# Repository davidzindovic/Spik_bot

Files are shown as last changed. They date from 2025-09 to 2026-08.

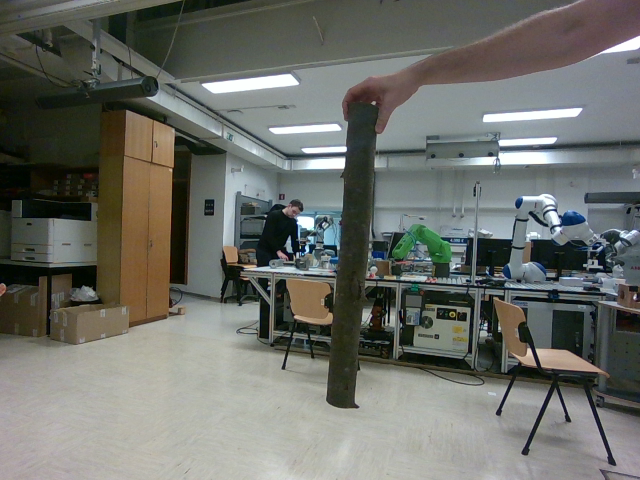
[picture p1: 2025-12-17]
RPI/zajeti_podatki/2barva.png

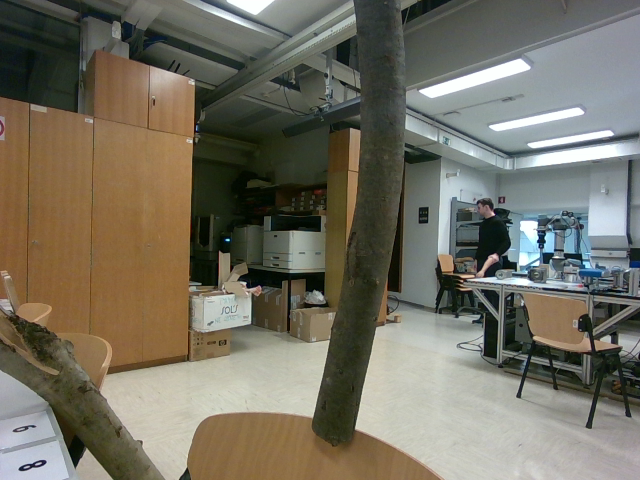
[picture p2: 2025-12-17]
RPI/zajeti_podatki/6barva.png

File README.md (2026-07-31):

# OPIS
SpikBot je manipulator namenjen robotizirani endoterapiji dreves, ki obratuje s pomočjo STM32H750B-DK razvojne plošče.
Drevo zazna s pomočjo Intel RealSense D455 RGB-D kamere, ki je povezana na osebni računalnik.
Po sadovnjaku premikamo manipulator s pomočjo AWD+AWS mobilne platforme, ki jo upravlja BeckHoff PLC krmilnik.

# REPOZITORIJ

- **Hardware** - Datoteke za električno shemo in električno vezje
- **Meritve** - Datoteke namenjene uvodnim meritvah sile in traja (arhivirano)
- **PC** - Programske datoteke, ki tečejo na osebnem računalniku
- **RPI** - Programske datoteke, ki tečejo na RaspberryPi (arhivirano)
- **STM32** - Programske datoteke, ki teče na STM32

# UPORABA

Napravo lahko uporabljamo v kombinaciji z računalnikom in STM32 krmilnikom preko tipkovnice.
Za Uporabo preko igralnega ploščka moramo povezati računalnik na mobilno platformo.
Navodila za uporabo se izpišejo ob začetku programa.

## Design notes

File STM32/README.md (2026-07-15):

Program deluje v okolju STM32CUBE_IDE različica ```1.16.1``` .

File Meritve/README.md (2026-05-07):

# Opis
Program beleži izmerjene podatke v .csv datoteko. Meritve opravlja STM32 razvojna plošča. Uporabnik lahko preko serijskega okna odprtega v Python okolju nastavlja željeni tlak in bere izmerjeni ter nastavjleni pritisk. Ob koncu programa (Ctrl+C) program shrani podatke in na podlagi shranjene .csv datoteke nariše grafikon.

## Potrebne knjižnice za zagon:
pyserial, matplotlib

## Sprememiti je potrebno:
- ```COM port (preverimo v Upravitelj naprav ali Device manager)```
- ```Pot do mape, v katero želimo shranjevati meritve```

# Potek meritve
Motor za vbod v deblo krmili bela ST razvojna plošča, pri čemer s pritiskom na modro tipko menjavamo smer potiska, s potenciometrom pa hitrost potiska.

Motor za črpalko krmili modra ST razvojna plošča z ekranom, ki tudi bere podatke iz senzorja (od primernega upora).

Za izvedbo meritve je potrebno vklopiti oba velika napajalnika na 230V, nato pa v poljubnem vrstnem redu še ST razvojni plošči (sta neodvisni ena od druge).

Ne pozabite tudi poskrbeti za primerno vmestitev dovodne cevi za tekočino (označena z maskircem in napisom "IN").

Zaženemo datoteko ```meritve_pritisk_stm32.py``` in spremljamo serijski monitor. Za vnos zaželjenega pritiska z levim klikom miške izberemo serijsko okno in nato le vpišemo zaželjeno številko (lahko z decimalno vrednostjo ali brez, npr. 5 ali 5.23) in nato potrdimo vnos s tipko Enter. Sprememnjena nastavitev za pritisk bo vidna v izpisu.

Ko želimo nehati z meritvijo pritisnemo CTRL+C, kar konča izvajanje Python skripte, shrani .csv datoteko meritev in izriše graf meritve.

## POMEMBNO
Na ta velikem laptopu v LR je desni USB vhod bližje uporabniku na COM6.

Če v serijskem oknu ne vidite izpisa v obliki: ```Izmerjeno: xxxxx.yyyyy``` ```Nastavljeno: aaaaaa.bbbbb``` poterm pritisnite črno tipko na modri ST razvojni plošči z ekranom.

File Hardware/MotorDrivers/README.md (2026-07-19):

To configure the StepperOnline CL57Y drivers, view the ```Konfiguracija driverja CL57Y.pdf``` file.

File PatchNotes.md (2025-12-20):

# 19.12.2025:
- zamenjani nekateri motorji
- jermenski sklop se premika zelo počasi
- motor na jermenskem sklopu ima reduktor in se vseeno greje. Morda potrebna opora zaradi akse?
- pumpa stestirana in dela. Festo 4mm cevi špilajo
- potreben nov cable managment
- potrebna izvedba kalibracijskega postopka
- potreben preizkus pridobivanja informacij iz RPI kamere in prenos na ST (prilagoditev kode)
- potreben preizkus majhnega krmilnika

# 14.12.2025:
- za zajet point cloud
- potrebno procesiranje point clouda (za točko in orientacijo vboda)
- 3d model nosilcev motorjev z reduktorji (todo)
- akse in gredi na stružnici za narest

# 14.11.2025:
- za poštimat settinge driverjev (najbolje dela POKI)
- direction switch dela probleme
- za stestirat on board driverček

# 26.10.2025:
- end switch pini spremenjeni na en kos na motor (prej bila dva). Prostanek rešen SW
- end SW za M1=PE3, M2=PH15, M3=PB4
- en switch pini imajo delujoče GPIO triggerje (potrebno urediti še ustrezen odziv)
- dodan direction pin (v SW) za M4

# 13.10.2025:
- ST UART skor konc
- RPI lahko transmita UART (se mi zdi)
- lahko controllam driverje (rabm še probat vse motorje)
- čakam akse
- realsense (z GUI) se odpre na RPI. Treba stuhtat data stream

# 02.09.2025:
- del inštalacije librealsense na RPI narejen
- delno narejena kinematika na STM32
- dodana funkcija za pumpanje tekočine
- v razmislek vzet merjenje prodora v deblo

# 27.8.2025:
- treba poštimat TIM12_CH2 (manjka IRQn)
- treba stestirat TIM12 z A4988

# 15.8.2025: 
- timer interupti (PWM) in inkrementacija pozicije deluje
- motor struct naštiman
- direction pini pripravljeni (ish)
  
TO DO: 
- dodatek end switchov (mby 2 na joint?)
- analogni pini za end switche
- koda za kalibracijo
- opencv camera
- rpi za kamero in serial do stm?? alpa kamera na stm

# 25.7.2025:
- sample code za motorje spisan z menjavo smeri

TO DO: 
- ~~tranzistorji/optocouplerji za TTL~~
- ~~test kode za motorje~~

useful link:
https://github.com/LAPSyLAB/STM32H7_Discovery_VIN_Projects/blob/main/STM32H750B-DK_VIN_Basic/Core/Src/main.c

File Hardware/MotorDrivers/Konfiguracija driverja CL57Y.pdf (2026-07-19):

Konfiguracija driverja CL57Y:

1. Prenesi software (https://drive.google.com/file/d/1CjlaODv1yihoZ95qD7p5dkwz2wUwD7tR/view?usp=sharing)
2. Pripravi 1x Arduino/STM32, 1x Driver CL57Y, 1x LR RMVS 2022 board za RS232 controllerjem (MAX3222), 1x USB A->USB B kabel, 1x razrezan USB B kabel
3. Poveži tako:

RS232 kabel na RS232 ploščico, USB A konec na PC.

Data kabla (bel in zelen) iz razrezanega USB B kabla gresta v skrajno levi stolpec female pinheaderja na RS232 ploščici. (glej pinout RMVS board – slika spodaj))

Poveži GND razrezanega USB B kabla na RS232 ploščico.

Poveži GND Arduinota/STMja na GND RS232 ploščice.

Poveži 3V3 na VCC RS232 boarda (glej pinout RMVS board).

USB B konec razrezanega kabla poveži na CL57Y driver. Na driverju naj bo 3 stikalo v ON legi (glej puščico, na dol spuščeno).

Driver naj bo napajan z 28+V, pripeljani naj bodo v V+ V- (pod »High Voltage« del).

Driver naj ima vedno 3. tipko obrnjeno dol (ON position). Leve 4 tipke so za nastavitve delovanja, desne 4 za ločljivost (glej datasheet).

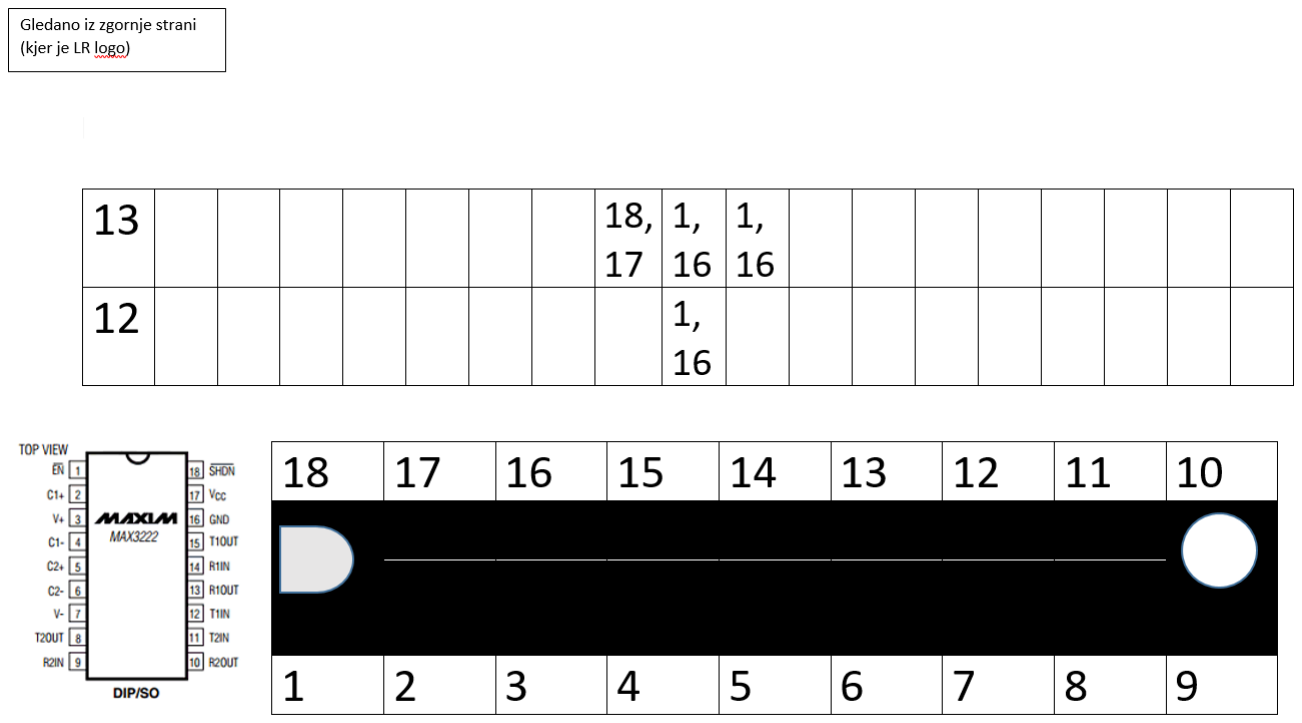
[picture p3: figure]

V software-u boste ob zagonu izbrali ploščico CL57Y in nato Connect. Za tem izbereš pravilen COM port in baud 115200. Nato Connect. Zelen bar se pojavi in naloži parametre. Operation mode naj bo na 1 (Open loop). Za zapis klikneš »Write Check« in nato check/retry (mislim da celo ni potrebno). Priporočam, da se preveri če je pravilno konfiguriran s klikom na »Disconnect« in nato še enkrat »Connect«.

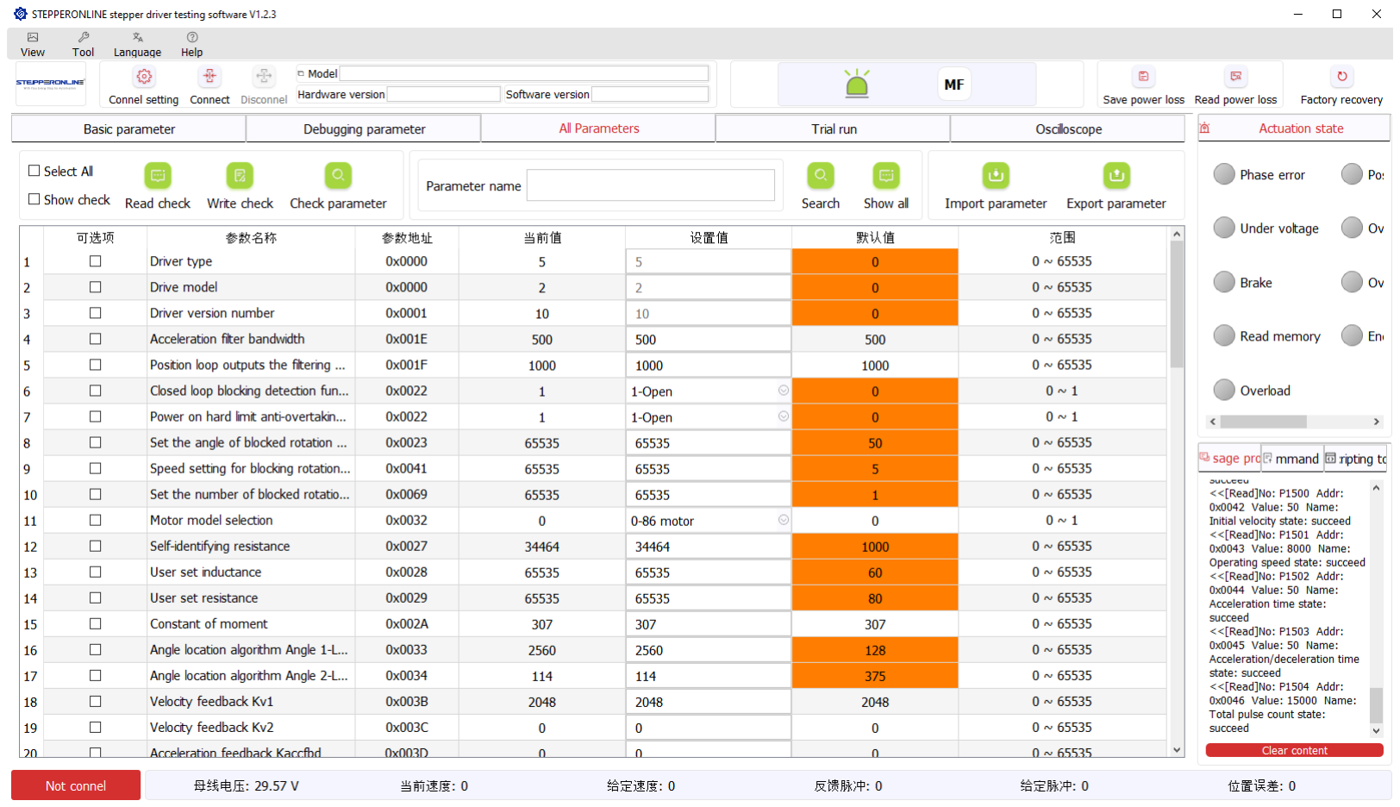
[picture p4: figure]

Podrobneje:

Nastavitve lahko urejaš v 5. stolpcu in nekatere nastavitve lahko nastaviš tudi izven omejenega območja (navedeno v zadnjem stolpcu). Izbrane nastavitve zapišemo z »Write check«, pri čemer je pred zapisom potrebno odkljukati kaj vse želimo zapisati (najlažje je izbrati »Select All« zgoraj levo). Enako velja za branje (beremo iz driverja).

4. stolpec prikazuje prebrane oz. trenutne vrednosti, 6. stolpec pa default vrednosti.

Nastavitve se lahko izvozi v .csv datoteko s pomočjo »Export parameter« gumba zgoraj desno. Lahko se jih tudi uvozi (npr. po priklopu drugega gonilnika) s pomočjo »Import parameter« in nato izbere (»Select All«) in zapiše z »Write Check«.

Ovire lahko povzroči zapis »Operation Mode« vrstice. Če zapišemo to vrstico, damo disconnect in odklopimo napajanje (+28 V) in nato priključimo nazaj ter ponovno povežemo gonilnik s connect, ugotovimo, da je Operation Mode kar je bil pred zapisom (v mojem primeru 4 - Vector). To lahko rešimo tako, da:

1. Nastavimo željen Operation Mode.
2. Pritisnemo »Save Power Loss« in počakamo da konča s shranjevanjem.
3. Zapišemo parameter Operation Mode (ali vse) z »Write Check«

4. Preberemo parameter (ali vse) z »Read Check«.
5. Potrdimo prebrane vrednosti z desnim klikom v vrstici parametra »Operation Mode«, pri čemer moramo biti pozorni na izpis v »Message prompt« spodaj desno. Ob desnem kliku bi se moralo izpisati
<<[Read]No: P0100 Addr: 0x0024 Value: 1 Name: Operation mode state: succeed
6. Za ziher lahko še parkrat izvedete 5. korak in tudi zapišete parameter z »Write Check«.
7. Odklopite +28V napajanje in ga priklopite nazaj na driver. Ob zagonu boste izbrali ploščico in dali »Connect«, nato bo program prebral parametre in vam jih izpisal. V kolikor se parametri ujemajo, ste zmagali ☺

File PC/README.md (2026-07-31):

Za preizkus posameznih sklopov uporabite datoteke iz **Vision** ali **MobilnaPlatforma** map.

Za vožnjo uporabite ```mobilna_drive_main.py```.

Za uporabo končnega programa uporabite ```main.py```, v kolikor želite opravljati meritve s postanki po vsakem delu pa uporabite ```main_za_meritve.py```

Osebni računalnik mora biti povezan preko RJ45 vodnika na BeckHoff krmilnik (zgornji ethernet port), na STM32 (nastavitev primeren COM) in Intel RealSense kamero.

Posebna nastavitev je *disparityShift*, ki je namenjena nastavljanju vidnega območja kamere.

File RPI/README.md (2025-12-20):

# Knjižnice
Za poenostavljanje programa so temu namenjene knjižnice za:
- namestitev potrebnih knjižnice = ```lib_init.py```
- serijsko komunikacijo z STM32 = ```spik_bot_serial.py```
- obdelavo shranjenih slik = ```data_capture_and_process.py```
- zajem in shranjevanje slik = ```capture_and_save_images.py```

# Launch realsense GUI
```realsense-viewer```

# Virtual environment
Launch:
```
python -m venv virtual_environment_name
source virtual_environment_name/bin/activate
```

on lr@spikbot the venv is named "okolje"

Shutdown virtual environment:
```deactivate```

# Zajeti podatki
V mapi ```zajeti_podatki``` so pari barvnih in globinskih slik skupaj s programskimi datotekami, ki so po korakih prispevale k nastanku ```data_capture_and_process.py```.
Program ```capture_and_save_images.py``` je namenjen le zajemu in shranjevanju podatkov v podmapo ```zajeti_podatki```.

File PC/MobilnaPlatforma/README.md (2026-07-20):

Za upravljanje mobilne platforme preko Python ukazov je potrebno:

- povezati Beckhoff krmilnik na računalnik preko UTP kabla (zgornji priključek na krmilniku)
- namestiti knjižnico *pyads* s pomočjo ukaza ```pip install pyads```
- vzpostaviti Route s pomočjo TwinCAT programske opreme (glej poglavje POVEZAVA)
- spisati kodo s primernimi ukazi za pisanje/branje

Pozor! Koda mora konstantno pošiljati timestamp (številko cikla), da koda deluje! (glej primer)

# POVEZAVA
V primeru uporabe FANUC prenosnika bodo nastavitve verjetno:
```
LOKALNI_AMS_ID = "192.168.65.121.1.1"  # AMS_ID računalnika
PLC_IP = "192.168.64.200"              # IP krmilnika
PLC_AMS_ID = "169.254.220.1.1.1"       # AMS ID krmilnika
```

IP krmilnika je potrebno nastaviti kot statičnega:

1. Odpreš *Nadzorna plošča* (angl. Control Panel)
2. Navigiraš v podmeni *Network and Internet* in za tem v *Network and Sharing Center*
3. Na strani najdeš *Change adapter setting*
4. Desni klik na opcijo *Ethernet* in izbereš *Properties*
5. Najdeš *Internet Protocol Verison 4* in izbereš ter odpreš *Properties*
6. V novem oknu izbereš *Use the following IP address:*, z nastavitvami:
```
IP address: 192.168.64.200
Subnet Mask 255.255.255.0
Default Gateway: 192.168.64.1
```
7. Izbereš *OK* in *Close*.
8. Nato onemogočiš Ethernet z *desni klik na Ethernet* in *Disable*
9. Počakaš par sekund, nato spet omogočiš z *desni klik na Ethernet* in *Enable*

Za informacijo o AMS ID krmilnika lahko (z zagnanim TwinCAT) spodaj desno v orodni vrstici z *desni klik na TwinCAT Config Mode* in izbiro *Route* in *Edit Routes*. Zanima nas CX-2A5526, v tisti vrstici najdemo informacije.

# PYTHON UKAZI
```
pyads.open_port()
pyads.close_port()
plc = pyads.Connection(PLC_AMS_ID, pyads.PORT_TC3PLC1, PLC_IP)
plc.write_by_name('MAIN.MasterContol.data.mode', 1, pyads.PLCTYPE_LREAL)
prebran_mode = plc.read_by_name("MAIN.mode", pyads.PLCTYPE_LREAL)
plc.close()
```
Pri ukazih za branje in pisanje bodite pozorni, kje lahko dostopate do željene spremenljivke. Če je to MAIN, potem je potrebno pred nazivom spremenljivke kot je prikazana v samem programu, dopisati še "MAIN". Pri tem se sklicujte na deklaracijo spremenljivke.

## UKAZI ZA PLATFORMO:

### Vklop motorjev
  ```
plc.write_by_name('MAIN.MasterContol.data.mode', 1, pyads.PLCTYPE_LREAL)
plc.write_by_name('MAIN.MasterContol.data.masterSwich', 1, pyads.PLCTYPE_LREAL)
```
### Zaustavitev koles (vrtenje)
```
plc.write_by_name('MAIN.MasterContol.data.modeKolesHub[0]', 2, pyads.PLCTYPE_LREAL)
plc.write_by_name('MAIN.MasterContol.data.modeKolesHub[1]', 2, pyads.PLCTYPE_LREAL)
plc.write_by_name('MAIN.MasterContol.data.modeKolesHub[2]', 2, pyads.PLCTYPE_LREAL)
plc.write_by_name('MAIN.MasterContol.data.modeKolesHub[3]', 2, pyads.PLCTYPE_LREAL)
```

### Vklop steeringa
```
plc.write_by_name('MAIN.MasterContol.data.steeringMode', 1, pyads.PLCTYPE_LREAL)
```
Pozor: kolesa se ob tej komandi poravnajo naravnost

### Branje spremenljivk
```
prebran_mode = plc.read_by_name("MAIN.mode", pyads.PLCTYPE_LREAL)
```

### Zasuk koles (vseh?)
```
kot=10
plc.write_by_name('STEERING.WHEEL_1_ANG_REF', kot, pyads.PLCTYPE_LREAL)
```
### Hitrost vrtenja koles
```
set_speed=10
plc.write_by_name('MAIN.CartContol.data.hitrost_ms', set_speed, pyads.PLCTYPE_LREAL)
```

### Pošiljanje TimeStampa
```
timestamp+=1
 plc.write_by_name('MAIN.CartContol.data.timeStamp', timestamp, pyads.PLCTYPE_LREAL)
```
# Ukazi na igralnem ploščku:
- LB = Dead Man Switch (zadaj levo, blizu D-pada)
- D-pad = LEVO (zasuk koles v levo), DESNO (zasuk koles v desno) če smo v načinu 1
- Desni Joystick = NAPREJ (nastavljanje hitrosti naprej), NAZAJ (nastavljanje hitrosti za vzvratno vožnjo)
- START = preklop med načinoma ZAGON in STOP
- A = tempomat (ohrani trenutno hitrost, kot bi konstantno držali joystick)
- Y = način 1 (premikanje naprej nazaj z zavijanjem)
- X = način 2 (vrtenje na mestu)
- B = način 5 (stacionarno stanje)

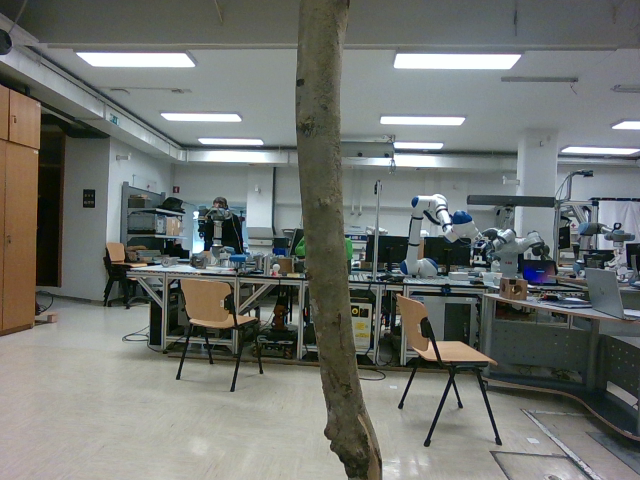
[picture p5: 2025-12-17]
RPI/zajeti_podatki/8barva.png

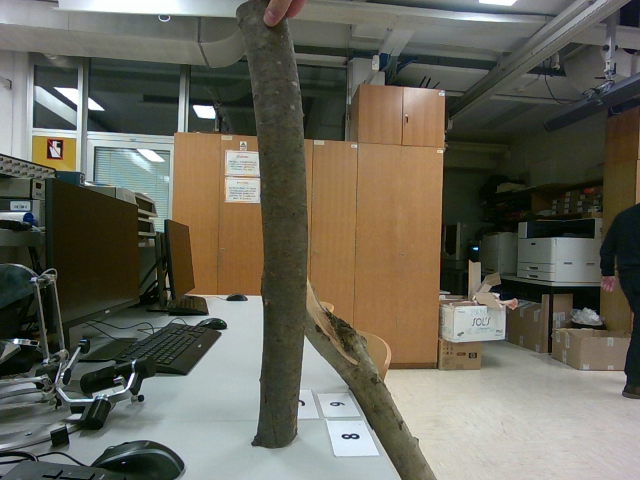
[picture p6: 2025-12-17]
RPI/zajeti_podatki/4barva.png

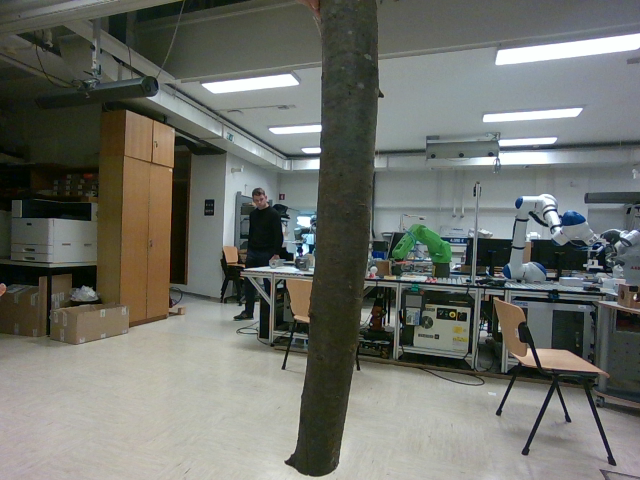
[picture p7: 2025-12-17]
RPI/zajeti_podatki/3barva.png

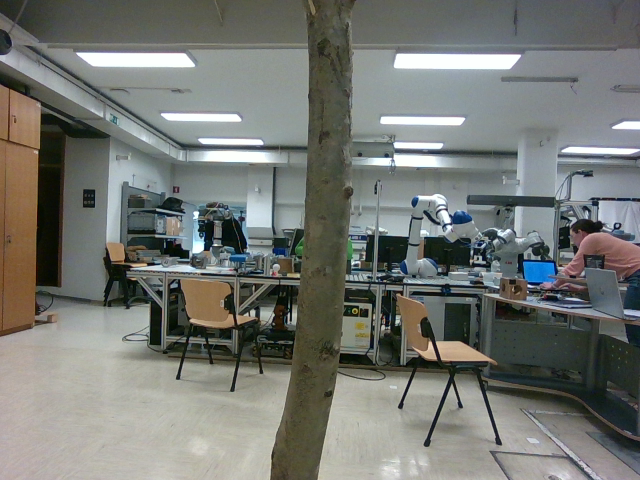
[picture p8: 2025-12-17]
RPI/zajeti_podatki/7barva.png

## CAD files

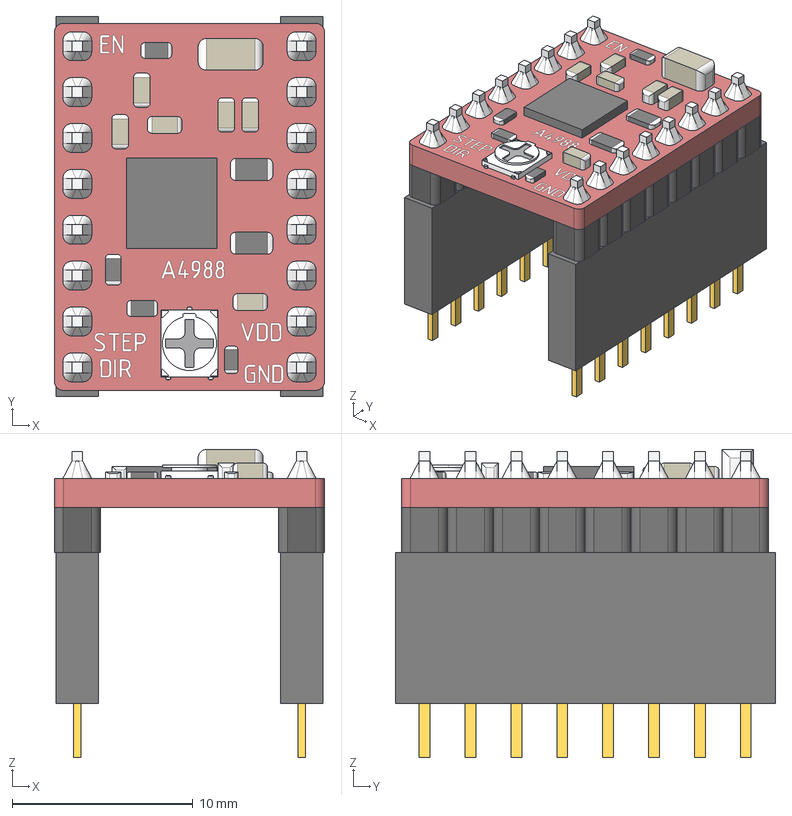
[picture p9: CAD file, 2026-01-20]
Hardware/PCB/A4988-Stepper-Driver-Socketed.stp
15.0 x 21.1 x 17.1 mm

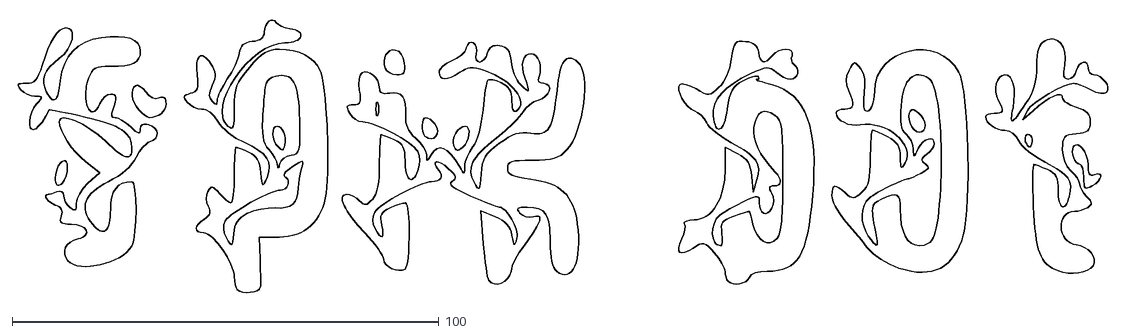
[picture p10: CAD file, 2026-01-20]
Hardware/PCB/SpikBotLogo.dxf
256.6 x 65.2

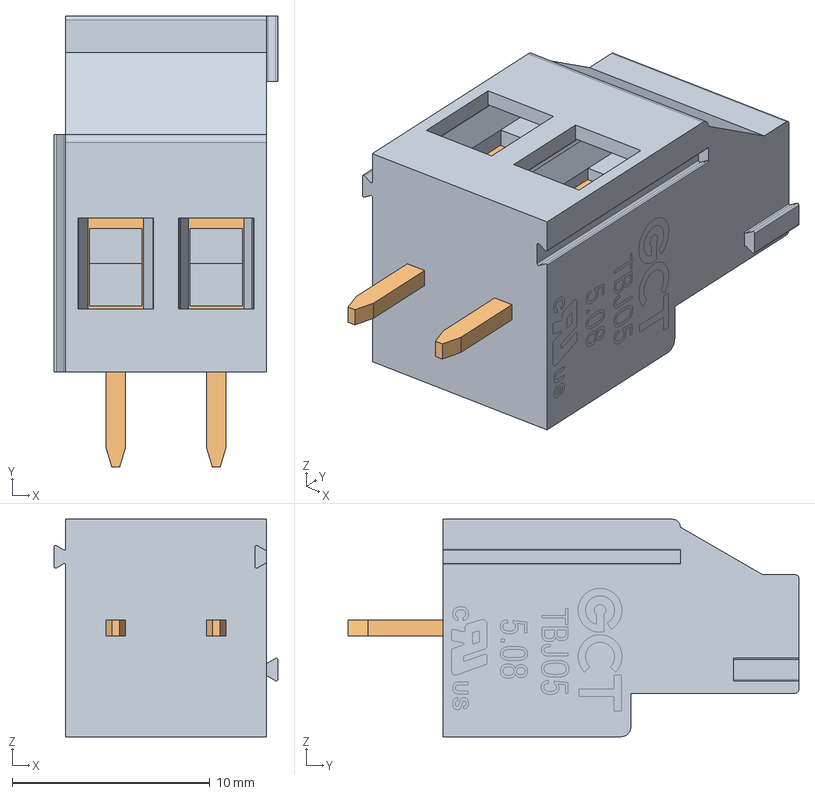
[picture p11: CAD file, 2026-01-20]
Hardware/PCB/connector_pobarvan.stp
11.3 x 22.8 x 11.0 mm

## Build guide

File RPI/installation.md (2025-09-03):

# ostal sem na:
Install RealSense SDK pyrealsense2 Python bindings for librealsense:
(v directory: ~/librealsense/build)

# zgled za kodo:
https://github.com/IntelRealSense/librealsense/issues/6628

https://github.com/IntelRealSense/librealsense/blob/master/wrappers/python/examples/python-tutorial-1-depth.py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

# realsense installation:
https://github.com/datasith/Ai_Demos_RPi/wiki/Raspberry-Pi-4-and-Intel-RealSense-D435

# USART:
Raspberry Pi 5 UART Setup
1. Enable UART on Raspberry Pi 5

The Raspberry Pi 5 has multiple UART options. The main ones are:

    ttyAMA0 - Primary UART (usually on GPIO 14/15)

    ttyS0 - Mini UART (secondary)

Enable UART in raspi-config:
bash

sudo raspi-config

    Select Interface Options → Serial Port

    Would you like a login shell to be accessible over serial? → No

    Would you like the serial port hardware to be enabled? → Yes

    Reboot when prompted

Alternatively, edit config files manually:
bash

sudo nano /boot/firmware/config.txt

Add these lines:
text

Enable primary UART
enable_uart=1

Disable Bluetooth to free up ttyAMA0 (optional)
dtoverlay=disable-bt

bash

sudo nano /boot/firmware/cmdline.txt

Remove any console=serial0,115200 or console=ttyAMA0,115200 entries to free the UART for your use.

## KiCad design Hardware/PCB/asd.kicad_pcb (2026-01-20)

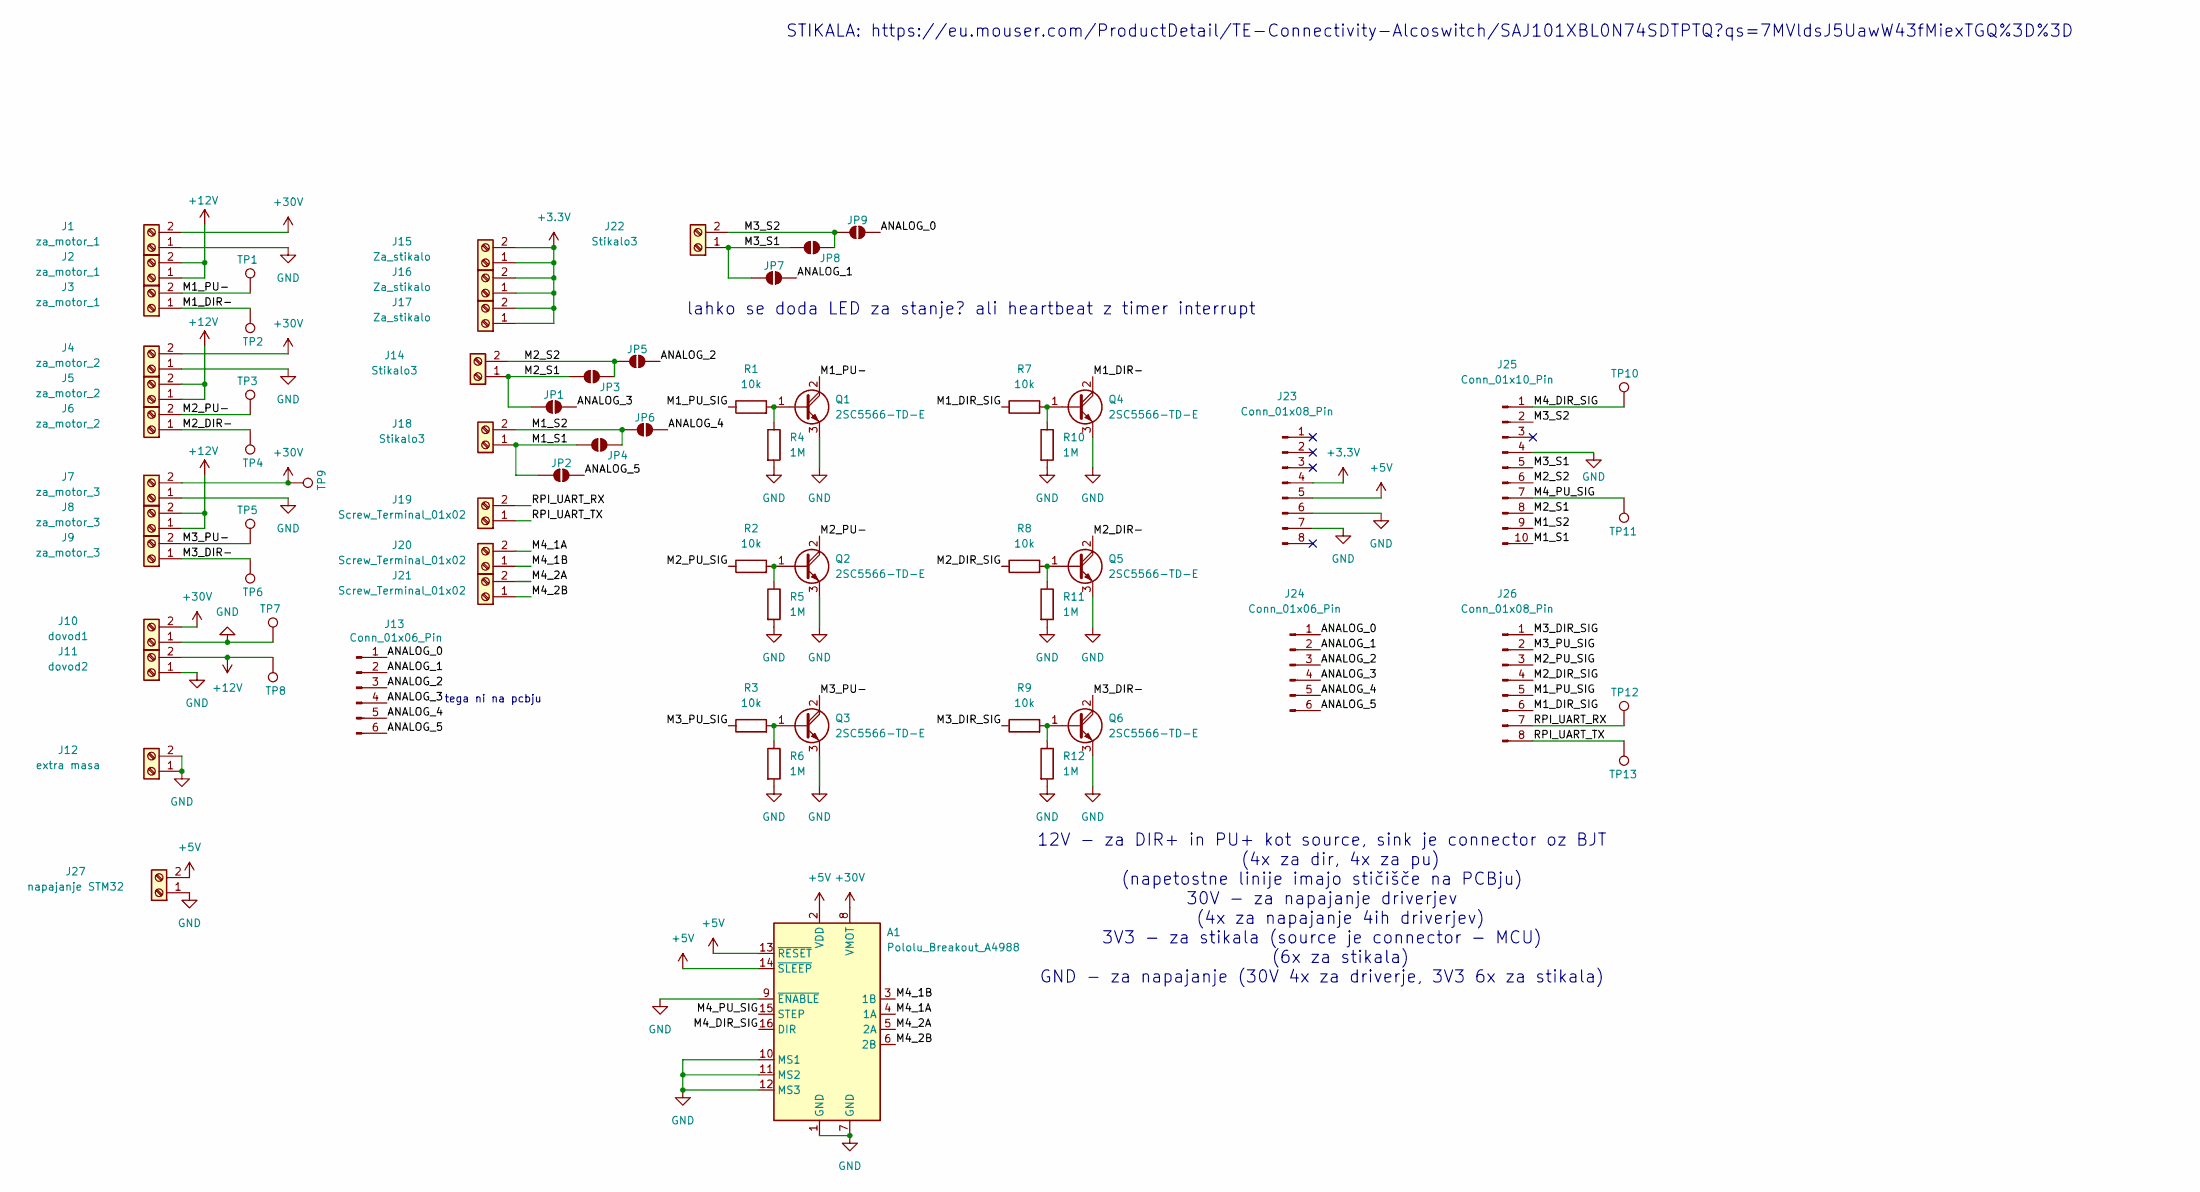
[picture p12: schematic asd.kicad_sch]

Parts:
A1: Pololu_Breakout_A4988; Pololu_Breakout-16_15.2x20.3mm
J1, J2, J3: za_motor_1; TerminalBlock_MetzConnect_Type073_RT02602HBLU_1x02_P5.08mm_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
J4, J5, J6: za_motor_2; TerminalBlock_MetzConnect_Type073_RT02602HBLU_1x02_P5.08mm_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
J7, J8, J9: za_motor_3; TerminalBlock_MetzConnect_Type073_RT02602HBLU_1x02_P5.08mm_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
J10: dovod1; TerminalBlock_MetzConnect_Type073_RT02602HBLU_1x02_P5.08mm_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
J11: dovod2; TerminalBlock_MetzConnect_Type073_RT02602HBLU_1x02_P5.08mm_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
J12: extra masa; TerminalBlock_MetzConnect_Type073_RT02602HBLU_1x02_P5.08mm_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
J13, J24: Conn_01x06_Pin; PinHeader_1x06_P2.54mm_Vertical
J14, J18, J22: Stikalo3; TerminalBlock_MetzConnect_Type073_RT02602HBLU_1x02_P5.08mm_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
J15, J16, J17: Za_stikalo; TerminalBlock_MetzConnect_Type073_RT02602HBLU_1x02_P5.08mm_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
J19, J20, J21: Screw_Terminal_01x02; TerminalBlock_MetzConnect_Type073_RT02602HBLU_1x02_P5.08mm_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
J23, J26: Conn_01x08_Pin; PinHeader_1x08_P2.54mm_Vertical
J25: Conn_01x10_Pin; PinHeader_1x10_P2.54mm_Vertical
J27: napajanje STM32; TerminalBlock_MetzConnect_Type073_RT02602HBLU_1x02_P5.08mm_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
JP1, JP2, JP3, JP4, JP5, JP6, JP7, JP8, JP9: SolderJumper_2_Open; SolderJumper-2_P1.3mm_Open_TrianglePad1.0x1.5mm
Q1, Q2, Q3, Q4, Q5, Q6: 2SC5566-TD-E; SOT-89-3
R1, R2, R3, R7, R8, R9: 10k; R_0805_2012Metric
R4, R5, R6, R10, R11, R12: 1M; R_0805_2012Metric
TP1, TP2, TP3, TP4, TP5, TP6, TP7, TP8, TP9, TP10, TP11, TP12, TP13: TestPoint; TestPoint_Pad_D2.5mm

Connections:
+3.3V: J15.1, J15.2, J16.1, J16.2, J17.1, J17.2, J23.4
+5V: A1.2 (VDD), A1.13 (~RESET), A1.14 (~SLEEP), J23.5, J27.2
+12V: J2.1, J2.2, J5.1, J5.2, J8.1, J8.2, J11.2, TP8.1
+30V: A1.8 (VMOT), J1.2, J4.2, J7.2, J10.2, TP9.1
/ANALOG_0: J13.1, J24.1, JP9.2 (B)
/ANALOG_1: J13.2, J24.2, JP7.2 (B)
/ANALOG_2: J13.3, J24.3, JP5.2 (B)
/ANALOG_3: J13.4, J24.4, JP1.2 (B)
/ANALOG_4: J13.5, J24.5, JP6.2 (B)
/ANALOG_5: J13.6, J24.6, JP2.2 (B)
/M1_DIR-: J3.1, Q4.2 (C), TP2.1
/M1_DIR_SIG: J26.6, R7.1
/M1_PU-: J3.2, Q1.2 (C), TP1.1
/M1_PU_SIG: J26.5, R1.1
/M1_S1: J18.1, J25.10, JP2.1 (A), JP4.1 (A)
/M1_S2: J18.2, J25.9, JP4.2 (B), JP6.1 (A)
/M2_DIR-: J6.1, Q5.2 (C), TP4.1
/M2_DIR_SIG: J26.4, R8.1
/M2_PU-: J6.2, Q2.2 (C), TP3.1
/M2_PU_SIG: J26.3, R2.1
/M2_S1: J14.1, J25.8, JP1.1 (A), JP3.1 (A)
/M2_S2: J14.2, J25.6, JP3.2 (B), JP5.1 (A)
/M3_DIR-: J9.1, Q6.2 (C), TP6.1
/M3_DIR_SIG: J26.1, R9.1
/M3_PU-: J9.2, Q3.2 (C), TP5.1
/M3_PU_SIG: J26.2, R3.1
/M3_S1: J22.1, J25.5, JP7.1 (A), JP8.1 (A)
/M3_S2: J22.2, J25.2, JP8.2 (B), JP9.1 (A)
/M4_1A: A1.4 (1A), J20.2
/M4_1B: A1.3 (1B), J20.1
/M4_2A: A1.5 (2A), J21.2
/M4_2B: A1.6 (2B), J21.1
/M4_DIR_SIG: A1.16 (DIR), J25.1, TP10.1
/M4_PU_SIG: A1.15 (STEP), J25.7, TP11.1
/RPI_UART_RX: J19.2, J26.7, TP12.1
/RPI_UART_TX: J19.1, J26.8, TP13.1
GND: A1.1 (GND), A1.7 (GND), A1.9 (~ENABLE), A1.10 (MS1), A1.11 (MS2), A1.12 (MS3), J1.1, J4.1, J7.1, J10.1, J11.1, J12.1, J12.2, J23.6, J23.7, J25.4, J27.1, Q1.3 (E), Q2.3 (E), Q3.3 (E), Q4.3 (E), Q5.3 (E), Q6.3 (E), R4.2, R5.2, R6.2, R10.2, R11.2, R12.2, TP7.1
unnamed: Q1.1 (B), R1.2, R4.1
unnamed: Q2.1 (B), R2.2, R5.1
unnamed: Q3.1 (B), R3.2, R6.1
unnamed: Q4.1 (B), R7.2, R10.1
unnamed: Q5.1 (B), R8.2, R11.1
unnamed: Q6.1 (B), R9.2, R12.1

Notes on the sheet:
tega ni na pcbju
12V - za DIR+ in PU+ kot source, sink je connector oz BJT (4x za dir, 4x za pu) (napetostne linije imajo stičišče na PCBju) 30V - za napajanje driverjev (4x za napajanje 4ih driverjev) 3V3 - za stikala (source je connector - MCU) (6x za stikala) GND - za napajanje (30V 4x za driverje, 3V3 6x za sti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
lahko se doda LED za stanje? ali heartbeat z timer interrupt
STIKALA: https://eu.mouser.com/ProductDetail/TE-Connectivity-Alcoswitch/SAJ101XBL0N74SDTPTQ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

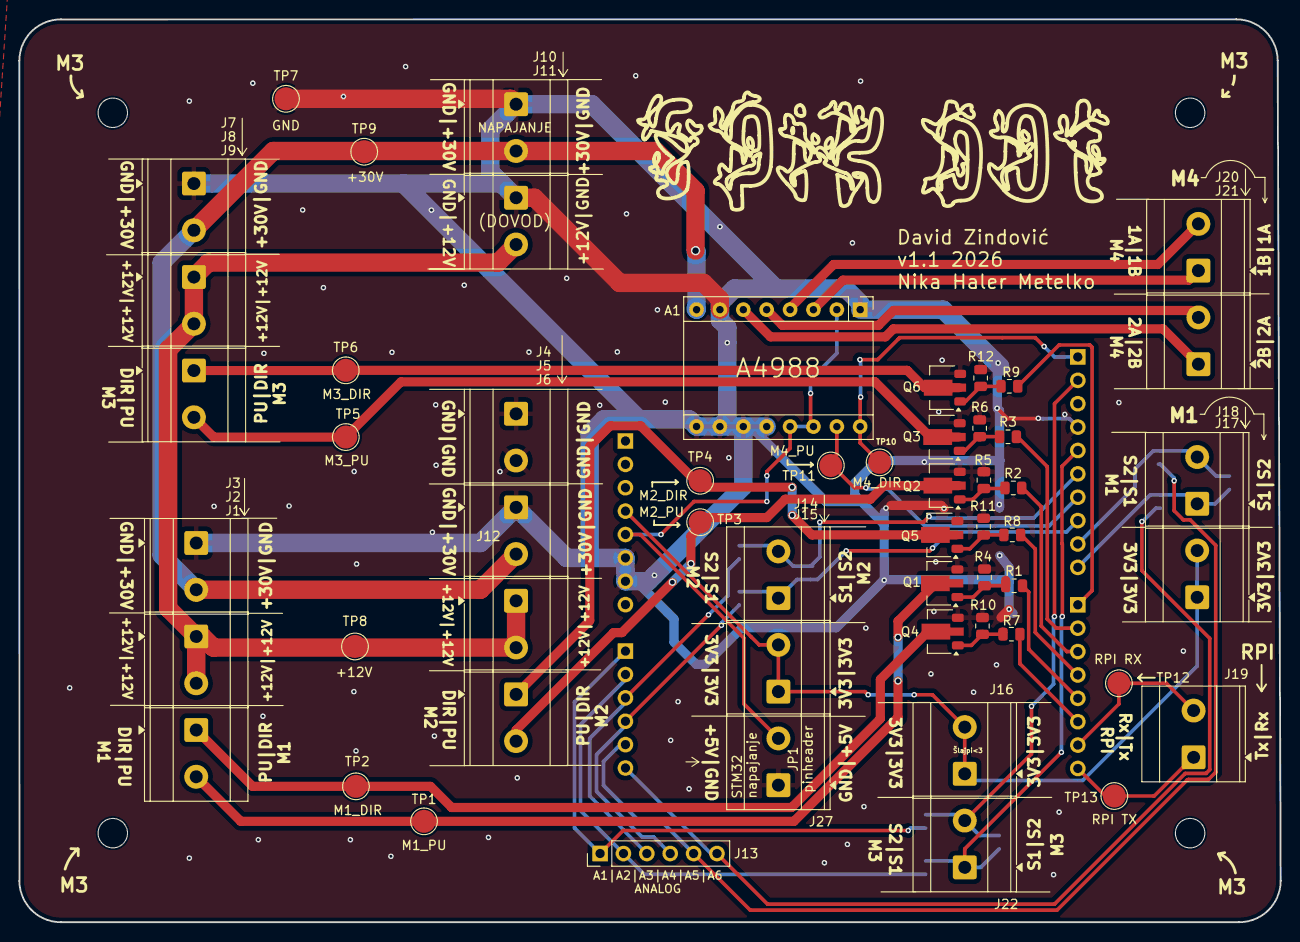
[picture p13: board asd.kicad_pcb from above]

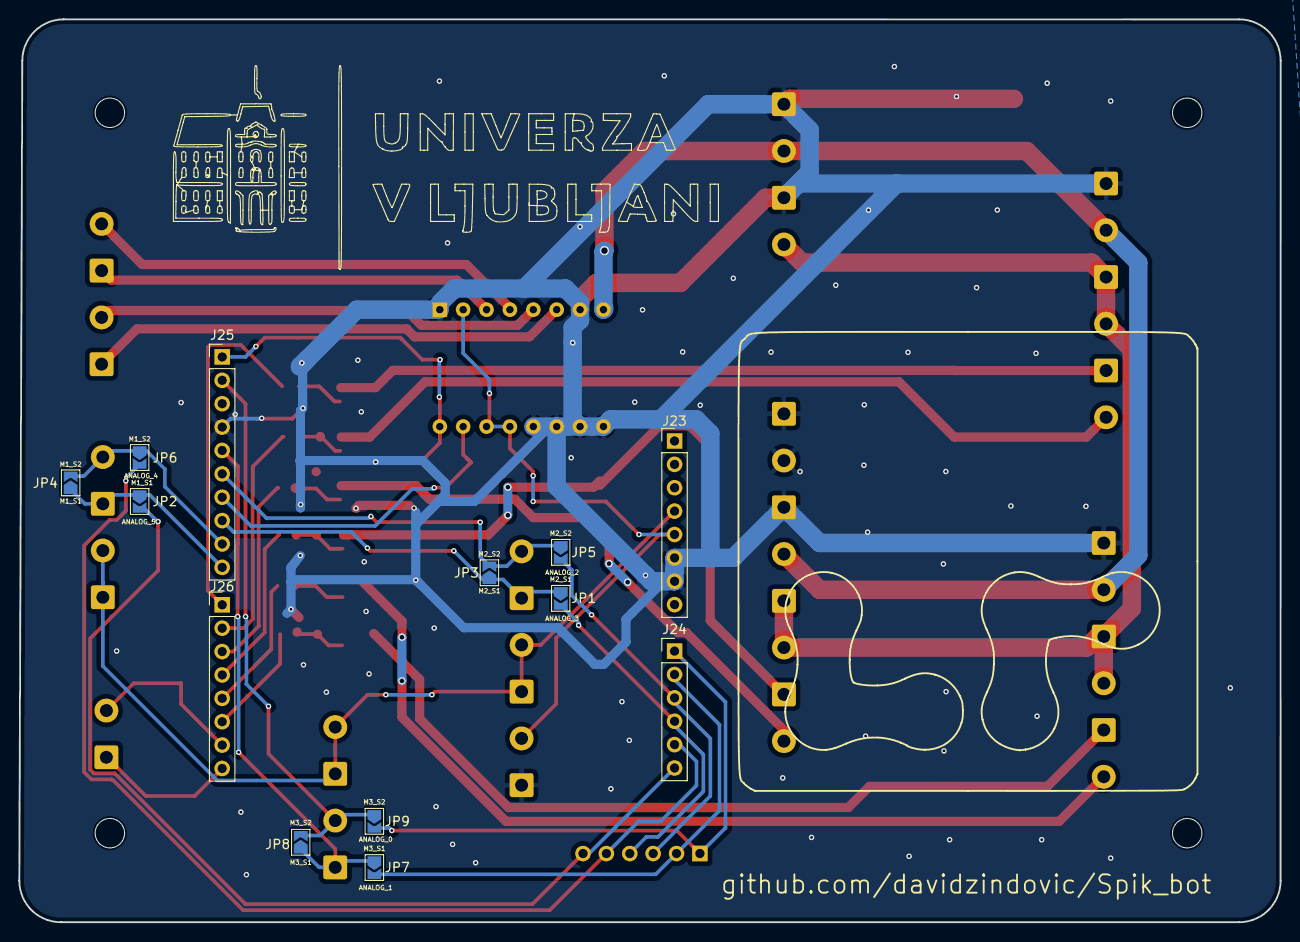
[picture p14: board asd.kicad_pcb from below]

Board: 2 copper layers, 137.0 x 98.1 mm, 69 parts (13 on the bottom side), 43 nets.

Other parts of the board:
REF: MountingHole_3.2mm_M3

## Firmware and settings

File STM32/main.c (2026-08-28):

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
/* Includes ------------------------------------------------------------------*/
#include "main.h"
#include "cmsis_os.h"//

/* USER CODE BEGIN Includes */
#include "stlogo.h"
#include "app_timers.h"

//#include "stm32_lcd.h"

#include <stdio.h>

#include "uart.h"
#include "retarget.h"
#include "dma.h"

/* USER CODE END Includes */

/* USER CODE BEGIN PTD */
typedef struct {
    uint32_t max_speed;
    uint32_t current_speed;

    _Bool direction;
	_Bool direction_plus;
	_Bool direction_minus;
	uint8_t allowed_direction;//2=any, sicer je limited=+/-

	uint32_t num_steps_for_switch_release;

    uint16_t direction_pin;
    GPIO_TypeDef* direction_port;

    TIM_HandleTypeDef* timer;
    uint32_t timer_channel;
	uint32_t frequency;

    uint16_t motor_pin;
    GPIO_TypeDef* motor_port;

    int max_position; //in numbers of steps
    int starting_position;
    int position;
    int target_position;
    int home_position;
    int offset;
	_Bool running;

    _Bool reset_requested;
    _Bool reset_completed;

    uint16_t end_switch_pin;
    GPIO_TypeDef* end_switch_port;
	_Bool end_switch_triggered;

	int unit_conversion; //number of step per mm or deg
	int travel_length; //maximum travel length distance of segment

	uint32_t num_steps_per_turn; //number of steps per rotation (360°)

	/*uint32_t num_turns_from_encoder;

	//encoder only one cable per channel due to lack of pins

	uint32_t encoder_A_state;
	uint16_t encoder_A_pin;
    GPIO_TypeDef* encoder_A_port;
	uint32_t encoder_B_state;
	uint16_t encoder_B_pin;
    GPIO_TypeDef* encoder_B_port;
	_Bool encoder_Z_state;
	uint16_t encoder_Z_pin;
    GPIO_TypeDef* encoder_Z_port;
    */

}motor_struct_t;

typedef struct {
    uint8_t pin_number;      // A0, A1, etc.
    uint32_t adc_channel;    // ADC channel number
    ADC_HandleTypeDef* hadc; // ADC handle to use
    uint32_t gpio_pin;       // GPIO pin
    GPIO_TypeDef* gpio_port; // GPIO port
    char* name;              // Pin name for display
} analog_pin_config_t;
/* USER CODE END PTD */

/* USER CODE BEGIN PD */
#define VL53L0X_ADDR 0x52  // 8-bitni naslov (0x29 << 1)
#define VL53L0X_REG_IDENTIFICATION_MODEL_ID 0xC0
#define VL53L0X_REG_VHV_CONFIG_PAD_SCL_SDA__EXTSUP_HV 0x89
#define VL53L0X_REG_SYSTEM_SEQUENCE_CONFIG 0x01
#define VL53L0X_REG_RESULT_RANGE_STATUS 0x14
#define VL53L0X_REG_SYSTEM_INTERRUPT_CLEAR 0x0B

/* ---- DC motor PWM controller (distance-regulated) ---- */

//podatki za tof pozicijo bolj nazaj
//do konca porinjena igla
//#define DC_DIST_MIN_MM      88U //83+35     /* below this: stop (unless reversing out) */

//#define DOLZINA_IGLE 20U
//#define MAX_IZTEG 71U

//pr tej razdalji se igla dotika debla
//#define DC_DIST_MAX_MM      108U//113+50=max reach//130U    /* above this: stop (unless forwarding back) */

//#define TOF_OFFSET 5U

/*
 * TOF senzor razdalje:
 * Od TOF do sredine konusa = 4.84+72.51+11 = 88.35 mm
 * Od TOF do konc igle = 4.84+72.51+30.61 = 107.96 mm
 * dolzina igle = 20 mm
 * max izteg igle = 71 mm
 */
/*
 * tof test:
 * les od konca bloka 31.5 mm (čis pr igli skor)
 * tof reading ~107 mm
 */
//----------------------------------------

//podatki za tof pozicijo bolj naprej
//do konca porinjena igla
#define DC_DIST_MIN_MM      66U//v resnici:67U     /* below this: stop (unless reversing out) */

#define DOLZINA_IGLE 19U//od sredine konusa
#define MAX_IZTEG 57U//124-86+19=57U//v resnici: 71U

//pr tej razdalji se igla dotika debla
#define DC_DIST_MAX_MM      87U   /* above this: stop (unless forwarding back) */

//#define TOF_OFFSET 5U

/*
 * TOF senzor razdalje:
 * Od TOF do sredine konusa = 4.32+50.25+11 = 65.57 mm
 * Od TOF do konc igle = 4.32+50.25+11+19 = 84.57 mm
 * dolzina igle = 19 mm
 * max izteg igle = 71 mm
 */
/*
 * tof test:
 * les od konca bloka 31.5 mm (čis pr igli)
 * tof reading ~87 mm
 */
//----------------------------------------


/* X-NUCLEO-IHM04A1 H-bridge pin mapping (STM32H750B-DK Arduino header)
 *
 *  A6 = PA6  → IN1: TIM13_CH1 (AF9)  – H-bridge input 1  (PWM)
 *  A1 = PF8  → IN2: GPIO output       – H-bridge input 2  (direction)
 *       Forward  : IN1 = PWM,  IN2 = LOW
 *       Reverse  : IN1 = 0,    IN2 = HIGH
 *
 *  A3 = PA1  → direction-change button, EXTI1, active LOW + pull-up
 *
 *  Note: TIM13_CH1 je na PA6 (AF9) — PF8 nima timer AF na STM32H750XB.
 *        PF8 se uporablja kot navaden GPIO za smer.
 */
#define DC_IN1_PORT         GPIOH
#define DC_IN1_PIN          GPIO_PIN_15
#define DC_IN2_PORT         GPIOB
#define DC_IN2_PIN          GPIO_PIN_4

#define DC_TIM_PERIOD       999U    /* ARR  → 1000 steps resolution              */
#define DC_TIM_PRESCALER    199U    /* 200 MHz / 200 / 1000 = 1 kHz PWM freq     */
/* USER CODE END PD */

#if defined ( __ICCARM__ ) /*!< IAR Compiler */
#pragma location=0x30000000
ETH_DMADescTypeDef  DMARxDscrTab[ETH_RX_DESC_CNT]; /* Ethernet Rx DMA Descriptors */
#pragma location=0x30000080
ETH_DMADescTypeDef  DMATxDscrTab[ETH_TX_DESC_CNT]; /* Ethernet Tx DMA Descriptors */

#elif defined ( __CC_ARM )  /* MDK ARM Compiler */

__attribute__((at(0x30000000))) ETH_DMADescTypeDef  DMARxDscrTab[ETH_RX_DESC_CNT]; /* Ethernet Rx DMA Descriptors */
__attribute__((at(0x30000080))) ETH_DMADescTypeDef  DMATxDscrTab[ETH_TX_DESC_CNT]; /* Ethernet Tx DMA Descriptors */

#elif defined ( __GNUC__ ) /* GNU Compiler */

//ETH_DMADescTypeDef DMARxDscrTab[ETH_RX_DESC_CNT] __attribute__((section(".RxDecripSection"))); /* Ethernet Rx DMA Descriptors */
//ETH_DMADescTypeDef DMATxDscrTab[ETH_TX_DESC_CNT] __attribute__((section(".TxDecripSection"))); /* Ethernet Tx DMA Descriptors */
#endif

//ETH_TxPacketConfig TxConfig;

ADC_HandleTypeDef hadc1;
ADC_HandleTypeDef hadc2;
ADC_HandleTypeDef hadc3;

//ETH_HandleTypeDef heth;

//FDCAN_HandleTypeDef hfdcan1;
//FDCAN_HandleTypeDef hfdcan2;

LTDC_HandleTypeDef hltdc;

QSPI_HandleTypeDef hqspi;

RNG_HandleTypeDef hrng;

//RTC_HandleTypeDef hrtc;

SAI_HandleTypeDef hsai_BlockA2;
SAI_HandleTypeDef hsai_BlockB2;

TIM_HandleTypeDef htim1;  // Example timer handles - adjust based on which timers you want to use
TIM_HandleTypeDef htim15;
TIM_HandleTypeDef htim3;
TIM_HandleTypeDef htim12;
TIM_HandleTypeDef htim6;
TIM_HandleTypeDef htim8;

MMC_HandleTypeDef hmmc1;

//SPI_HandleTypeDef hspi2;

UART_HandleTypeDef huart1;
UART_HandleTypeDef huart3;

//PCD_HandleTypeDef hpcd_USB_OTG_FS;

SDRAM_HandleTypeDef hsdram1;

/* Definitions for defaultTask */
osThreadId_t defaultTaskHandle;
const osThreadAttr_t defaultTask_attributes = {
  .name = "defaultTask",
  .stack_size = 128 * 4,
  .priority = (osPriority_t) osPriorityNormal,
};
/* USER CODE BEGIN PV */
__IO uint32_t ButtonState = 0;

volatile _Bool manual_mode = false;
volatile uint8_t manual_motor_idx = 0; // Trenutno izbran motor (0-3)

I2C_HandleTypeDef hi2c4;

volatile float target_pressure = 0.0f;     // Ciljni tlak iz UART3
volatile uint8_t uart3_rx_buffer[32];      // Buffer za sprejem
volatile uint8_t uart3_rx_index = 0;       // Indeks v bufferju
volatile uint8_t uart3_command_ready = 0;  // Flag, da je ukaz prejet
volatile uint8_t uart3_new_data = 0;       // Flag za novo sporočilo

uint16_t timer_val_start, timer_val_end;
uint16_t elapsed_1st, elapsed_2nd, elapsed_3rd;

uint8_t time_str1[60];
uint8_t time_str2[40];

/*
int position_m2=0;
int dir_m2=0;
int position_m3=0;
int dir_m3=0;
*/

extern TIM_HandleTypeDef htim1;
extern TIM_HandleTypeDef htim15;
extern TIM_HandleTypeDef htim3;
extern TIM_HandleTypeDef htim12;
extern TIM_HandleTypeDef htim8;

motor_struct_t motors[4]; // Declaration only

analog_pin_config_t analog_pins[6];

typedef enum { DC_DIR_FORWARD = 0, DC_DIR_REVERSE = 1 } dc_direction_t;

static TIM_HandleTypeDef       htim2;   /* unused – kept to avoid linker errors */
//static TIM_HandleTypeDef       htim8;  /* TIM13_CH1 → IN1 on PA6 (A6) */
volatile dc_direction_t        dc_direction    = DC_DIR_FORWARD;
volatile uint8_t               dc_dir_changed  = 0;

/* Nastavitve za avtomatski časovni premor in logiko odmika */
uint32_t dc_wait_time_ms = 5000;         /* Čas čakanja na točki obrata (5 sekund) */
uint32_t dc_stop_timestamp = 0;         /* Časovna značka, kdaj se je motor ustavil */
uint32_t dc_time_elapsed = 0;

typedef enum {
    DC_STATE_REGULATED = 0,             /* Normalno delovanje: senzor regulira hitrost */
    DC_STATE_WAITING,                   /* Motor je dosegel min razdaljo in čaka 5 sekund */
    DC_STATE_RETRACTING                 /* Motor se umika nazaj do maks razdalje */
} dc_state_t;

volatile dc_state_t dc_current_state = DC_STATE_REGULATED;

uint16_t trenutna_razdalja=2;
uint8_t false_read_tof=0;

volatile uint8_t uart_blocks_disabled = 0;  /* 1 = IGNORIRAJ UART BLOKADE (samostojno delovanje), 0 = ČAKAJ NA UART */

_Bool zagon_izvedbe = false;

/* USER CODE END PV */

void SystemClock_Config(void);
void PeriphCommonClock_Config(void);
static void MX_GPIO_Init(void);
static void MX_ADC1_Init(void);
static void MX_ADC2_Init(void);
static void MX_ADC3_Init(void);
static void MX_ETH_Init(void);
static void MX_FDCAN1_Init(void);
static void MX_FDCAN2_Init(void);
static void MX_FMC_Init(void);
static void MX_LTDC_Init(void);
static void MX_QUADSPI_Init(void);
static void MX_RTC_Init(void);
static void MX_SAI2_Init(void);
static void MX_SDMMC1_MMC_Init(void);
static void MX_SPI2_Init(void);
//static void MX_USB_OTG_FS_PCD_Init(void);
static void MX_RNG_Init(void);
static void CPU_CACHE_Enable(void);
void StartDefaultTask(void *argument);

static void MX_TIM1_Init(void);
static void MX_TIM15_Init(void);
static void MX_TIM3_Init(void);
static void MX_TIM12_Init(void);
/* USER CODE BEGIN PFP */
void stall(uint32_t duration_us);
void stop_all_motors(void);
void direction_change(uint8_t motor_number, _Bool direction);
void reset_motors(void);
void move_to_starting_position(uint8_t motor_number);
//_Bool move_effector(uint32_t x, uint32_t y, uint32_t orientation);
void update_global_coordinates(void);
_Bool read_switch(uint8_t motor_number);
void run_motor(uint8_t motor_number);
void stop_motor(uint8_t motor_number);
void pump_liquid(uint32_t ammount_of_liquid);
void test_motor(uint8_t motor_number);
void test_all_motors();
void demo_za_predstavitev();
void move_motor_2_end_switch(uint8_t motor_number, _Bool direction);
void calibrate_all_motors(void);

void process_encoder(uint8_t encoder_number, _Bool A, _Bool B, _Bool Z);

void HAL_TIM_PeriodElapsedCallback(TIM_HandleTypeDef *htim);
void TIM1_UP_IRQHandler(void);
void TIM15_IRQHandler(void);
void TIM3_IRQHandler(void);
void TIM8_BRK_TIM12_IRQHandler(void);
void Test_USART3(void);

void USART1_IRQHandler(void);
static void MX_USART1_UART_Init(void);
static void MX_USART3_UART_Init(void);

void izpis_v_serijc(char *sporocilo);
void uart_transmit(char *sporocilo);
char uart_receive(char *sporocilo);
void process_message(char message);

void uart_process_command(const char* command);
void motor_status(void);

void test_tipke_na_roke(void);
void receive_target_point(int *x_coordinate, int *y_coordinate, int* z_coordinate, int *phi);

static void MPU_Config(void);
void USART3_Pin_Init(void);

void configure_end_switch_interrupts(void);
//void EXTI2_IRQHandler(void);
void EXTI3_IRQHandler(void);
void EXTI2_IRQHandler(void);
void EXTI15_10_IRQHandler(void);
void EXTI9_5_IRQHandler(void);
void EXTI1_IRQHandler(void);
void HAL_GPIO_EXTI_Callback(uint16_t GPIO_Pin);
void HAL_TIM_PWM_MspInit(TIM_HandleTypeDef* htim_pwm);
//void USART_write(int ch);

//void UART_Write_String(char *p);

//uint32_t Read_ADC(ADC_HandleTypeDef* hadc);

void MX_ADC_Init_AnalogPins(void);
void configure_analog_pins(void);
uint16_t read_analog_pin(uint8_t pin_index);

float mapFloat(float x, float in_min, float in_max, float out_min, float out_max);
float izmeri_pritisk();
float nastavi_pritisk();
_Bool reguliraj_pritisk(float izmerjen_tlak, float zeljen_tlak,float toleranca, uint8_t stevilka_motorja);

void serial_print_string(const char* text);
void serial_print_uint16(uint16_t number);
void serial_print_float(float number);
void serial_print_empty_screen(void);

void USART3_IRQHandler(void);
float parse_float_from_string(const char* str);

static void MX_I2C4_Init(void);
void VL53L0X_Init(void);
uint16_t VL53L0X_ReadDistance(void);
void VL53L0X_LoadTuningSettings(void);
static HAL_StatusTypeDef vl_write(uint8_t reg, uint8_t val);
static HAL_StatusTypeDef vl_read(uint8_t reg, uint8_t *val);
static HAL_StatusTypeDef vl_read16(uint8_t reg, uint16_t *val);
static void VL53L0X_PerformSPADCalibration(void);
static void MX_TIM6_Init(void);
void TIM6_DAC_IRQHandler(void);
static void MX_TIM8_Init(void);
void VL53L0X_Diagnose(void);
void DC_Motor_Init(void);
void DC_Motor_Update(uint16_t distance_mm);
void DC_Motor_Set_Speed(int16_t speed);

void execute_robot_movement(void);
void pospravi_robota(void);
void robot_control_manually(void);

/* USER CODE END PFP */

/* USER CODE BEGIN 0 */
TS_Init_t *hTSs;

//#define BUFFER_SIZE 30

//char rx_buff[BUFFER_SIZE];
//char rcv_buff[30];

TS_Init_t *hTSs;

__attribute__((aligned(32))) char rx_buff[32];        // padded to cache line size
__attribute__((aligned(32))) uint8_t uart_rx_buffer[32];

uint32_t timing_uart = 0;
uint32_t limit_uart = 5; //mej osveževanja
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
int main(void) {

	CPU_CACHE_Enable();
	HAL_Init();

    SCB->CPACR |= ((3UL << 10*2) | (3UL << 11*2));
    __DSB();
    __ISB();

    SCnSCB->ACTLR |= (1UL << 1);
    __DSB();
    __ISB();

	/* Reset of all peripherals, Initializes the Flash interface and the Systick. */

	HAL_NVIC_SetPriority(SysTick_IRQn, 0, 0);  /* highest priority */
	HAL_NVIC_SetPriority(TIM6_DAC_IRQn, 4, 0);  /* lower than SysTick */


	uint32_t RNG_PTR[2];
	for(uint8_t i=0;i<30;i++)rx_buff[i]='\0';
	for(uint8_t i=0;i<30;i++)uart_rx_buffer[i]='\0';

	/* MCU Configuration--------------------------------------------------------*/

	/* Reset of all peripherals, Initializes the Flash interface and the Systick. */


	/* Configure the system clock */
	SystemClock_Config();
	PeriphCommonClock_Config();


	/* Configure the peripherals common clocks */
	//PeriphCommonClock_Config();

	/* Initialize all configured peripherals */

	__HAL_RCC_TIM1_CLK_ENABLE();
	__HAL_RCC_TIM3_CLK_ENABLE();
	__HAL_RCC_TIM15_CLK_ENABLE();
	__HAL_RCC_TIM12_CLK_ENABLE();
	__HAL_RCC_USART1_CLK_ENABLE();
	__HAL_RCC_ADC12_CLK_ENABLE();  // For ADC1 and ADC2
	__HAL_RCC_ADC3_CLK_ENABLE();    // For ADC3
	__DSB();
	__ISB();


	//GPIO initialization
	MX_GPIO_Init();
	if (!uart_blocks_disabled) {MX_USART3_UART_Init();}
	//HAL_UART_Receive_IT(&huart3, rx_buff_usb, 10);


	I2C4_BusRecovery();
	HAL_Delay(10);


	MX_I2C4_Init();      /* Ta funkcija nastavi PD12/PD13 v Alternate Function način */


	HAL_Delay(50);
	HAL_GPIO_WritePin(GPIOG, GPIO_PIN_6, GPIO_PIN_RESET); // Poskusi za trenutek sprostiti CS


	//serial_print_string("Skeniram naslove na I2C4 (8-bit format)...\r\n");
	char msg[32];
	for(uint16_t i = 1; i < 255; i++) {
		// STM32 HAL skener preverja sode (pisanje) naslove
		if(HAL_I2C_IsDeviceReady(&hi2c4, i, 1, 10) == HAL_OK) {
			//serial_print_string("Najdena naprava na 8-bit naslovu: 0x");
			//sprintf(msg, "%02X", i);
			//serial_print_string(msg);
			//serial_print_string("\r\n");
		}
	}
	//serial_print_string("Skeniranje koncano.\r\n");

	if (HAL_I2C_IsDeviceReady(&hi2c4, VL53L0X_ADDR, 5, 100) == HAL_OK) {
		//serial_print_string("TOF senzor VL53L0X zaznan, inicializiram...\r\n");
		VL53L0X_Init();
		HAL_Delay(100);
		VL53L0X_Diagnose();
		MX_TIM6_Init();
		MX_TIM8_Init();
		//DC_Motor_Init();
	} else {
		serial_print_string("Senzorja na 0x52 ni. Preskakujem init, da preprecim HardFault.\r\n");
	}


	MX_USART1_UART_Init();


	// Start receiving - THIS IS CRITICAL!
	//HAL_UART_Receive_IT(&huart1, rx_buff, 30);  // Receive 1 byte at a time
	SCB_InvalidateDCache_by_Addr((uint32_t*)rx_buff, 32);
	HAL_UART_Receive_IT(&huart1, (uint8_t*)rx_buff, 30);  // Receive 1 byte at a time

	HAL_UART_Receive_IT(&huart3, &uart_single_byte, 1);
    //Debug_USART1_Config();

	//Timer initialization
	MX_TIM1_Init();
	MX_TIM15_Init();
	MX_TIM3_Init();
	MX_TIM12_Init();
	//HAL_TIMEx_PWMN_Start(&htim8, TIM_CHANNEL_3);

	// Nastavi časovnike na višjo prioriteto (npr. 3), da lahko prekinjajo UART
	HAL_NVIC_SetPriority(USART3_IRQn, 5, 0); //?
	HAL_NVIC_SetPriority(TIM3_IRQn, 3, 0); //?
	//HAL_NVIC_SetPriority(TIM1_BRK_UP_TRG_COM_IRQn, 3, 0);

	/* USER CODE BEGIN 2 */
	// freq=100000 -> hitro
	// steps=40000 -> en obrat

	motors[0] = (motor_struct_t){
	    .max_speed = 10000,
	    .current_speed = 0,
	    .direction = 1,
		.direction_plus = 1,
		.direction_minus = 0,
		.allowed_direction=2,
		.num_steps_for_switch_release=1000, //spremeni
	    .direction_pin = GPIO_PIN_3,
	    .direction_port = GPIOG,//D2
	    .timer = &htim3,
	    .timer_channel = TIM_CHANNEL_1,
		.frequency = 30000,
	    .motor_pin = GPIO_PIN_6,//D3
	    .motor_port = GPIOA,
	    .max_position = 10000000,
		.starting_position = 5000,
	    .position = 0,
		.target_position=0,
		.offset=0,
		.running = false,
	    .reset_requested = false,
	    .reset_completed = false,
	    .end_switch_pin = GPIO_PIN_3,//D8
	    .end_switch_port = GPIOE,
		.end_switch_triggered = 0,
	    //.end_switch2_pin = GPIO_PIN_15,//D9
	    //.end_switch2_port = GPIOH,
		.unit_conversion=100, //steps per mm
		.travel_length=630, //mm
		.num_steps_per_turn=40000/*,
		.num_turns_from_encoder=0,
		.encoder_A_state = 0,
		.encoder_A_pin = GPIO_PIN_3,
	    .encoder_A_port = GPIOE,
		.encoder_B_state = 0,
		.encoder_B_pin = GPIO_PIN_3,
	    .encoder_B_port = GPIOE,
		.encoder_Z_state = 0,
		.encoder_Z_pin = GPIO_PIN_3,
	    .encoder_Z_port = GPIOE*/
	};
	motors[2] = (motor_struct_t){
		.max_speed = 10000,
		.current_speed = 0,
		.direction = 1,
		.direction_plus = 1,
		.direction_minus = 0,
		.allowed_direction=2,
		.num_steps_for_switch_release=1000, //spremeni
		.direction_pin = GPIO_PIN_1,
		.direction_port = GPIOK,//D4
		.timer = &htim1,
		.timer_channel = TIM_CHANNEL_1,
		.frequency = 30000,
		.motor_pin = GPIO_PIN_8,//D5
		.motor_port = GPIOA,
		.max_position = 10000000,
		.starting_position=5000,
		.position = 0,
		.target_position=0,
		.offset=90,//os vrtenja do konc spindla
		.running = false,
		.reset_requested = false,
		.reset_completed = false,
		.end_switch_pin = GPIO_PIN_3,//bilo 15
		.end_switch_port = GPIOD,//bilo H
		.end_switch_triggered = 0,
		//.end_switch1_pin = GPIO_PIN_4,//D10
		//.end_switch1_port = GPIOB,
	    //.end_switch2_pin = GPIO_PIN_2,//D12
	    //.end_switch2_port = GPIOI,
		.unit_conversion=100, //steps per mm
		.travel_length=105, //mm
		.num_steps_per_turn=40000/*,
		.num_turns_from_encoder=0,
		.encoder_A_state = 0,
		.encoder_A_pin = GPIO_PIN_3,
	    .encoder_A_port = GPIOE,
		.encoder_B_state = 0,
		.encoder_B_pin = GPIO_PIN_3,
	    .encoder_B_port = GPIOE,
		.encoder_Z_state = 0,
		.encoder_Z_pin = GPIO_PIN_3,
	    .encoder_Z_port = GPIOE*/
	};
	motors[1] = (motor_struct_t){
		.max_speed = 10000,
		.current_speed = 0,
		.direction = 1,
		.direction_plus = 1,
		.direction_minus = 0,
		.allowed_direction=2,
		.num_steps_for_switch_release=1000, //spremeni
		.direction_pin = GPIO_PIN_8,
		.direction_port = GPIOI,//D7
		.timer = &htim15,
		.timer_channel = TIM_CHANNEL_2,
		.frequency = 30000,
		.motor_pin = GPIO_PIN_6,//D6
		.motor_port = GPIOE,
		.max_position = 10000000,
		.starting_position=5000,
		.position = 0,
		.target_position=0,
		.offset=0,
		.running = false,
		.reset_requested = false,
		.reset_completed = false,
		.end_switch_pin = GPIO_PIN_2,//D10
		.end_switch_port = GPIOI,//prej PB4
		.end_switch_triggered = 0,
		//.end_switch1_pin = GPIO_PIN_13,//D14
		//.end_switch1_port = GPIOD,
		//.end_switch2_pin = GPIO_PIN_3,//D13
		//.end_switch2_port = GPIOD,
		.unit_conversion=100, //steps per deg
		.travel_length=60, //deg
		.num_steps_per_turn=40000/*,
		.num_turns_from_encoder=0,
		.encoder_A_state = 0,
		.encoder_A_pin = GPIO_PIN_3,
	    .encoder_A_port = GPIOE,
		.encoder_B_state = 0,
		.encoder_B_pin = GPIO_PIN_3,
	    .encoder_B_port = GPIOE,
		.encoder_Z_state = 0,
		.encoder_Z_pin = GPIO_PIN_3,
	    .encoder_Z_port = GPIOE*/
	};
	motors[3] = (motor_struct_t){ //max 50000 freq
		.max_speed = 10000, //pomembno za max pretok
		.current_speed = 0,
		.direction = 1,
		.direction_plus = 1,
		.direction_minus = 0,
		.allowed_direction = 2,
		.num_steps_for_switch_release=1000, //ne rabis tukaj
		.direction_pin = GPIO_PIN_12,
		.direction_port = GPIOD,//D15
		.timer = &htim12,
		.timer_channel = TIM_CHANNEL_2,
		.frequency = 100,
		.motor_pin = GPIO_PIN_15,//D11
		.motor_port = GPIOB,
		.max_position = 10000,
		.starting_position=5000,
		.position = 0,
		.target_position=0,
		.offset=0,//odmik od osi vrtenja v mm?
		.running = false,

		//NE UPORABLJAJ = IGNORIRAJ:
		.reset_requested = false,
		.reset_completed = false,


		//uporabljeno za dc motor:
		.end_switch_pin = GPIO_PIN_8,//D14
		.end_switch_port = GPIOF,
		.end_switch_triggered = 0,


		.unit_conversion=100, //steps per mm
		.travel_length=360, //deg
		.num_steps_per_turn=200/*,
		.num_turns_from_encoder=0,

		//NE UPORABLJAJ = IGNORIRAJ:
		.encoder_A_state = 0,
		.encoder_A_pin = GPIO_PIN_3,
	    .encoder_A_port = GPIOE,
		.encoder_B_state = 0,
		.encoder_B_pin = GPIO_PIN_3,
	    .encoder_B_port = GPIOE,
		.encoder_Z_state = 0,
		.encoder_Z_pin = GPIO_PIN_3,
	    .encoder_Z_port = GPIOE*/
		//konc prepovedi
	};

	// Initialize analog pins A0-A5
	configure_analog_pins();


	//usable IO: I2
	configure_end_switch_interrupts();

	/* Configure LED1 */
	//BSP_LED_Init(LED1);


	/* USER CODE END 2 */

	/* Infinite loop */
	/* USER CODE BEGIN WHILE */

	/*

	*/
	stop_all_motors();

	//reset_motors();

	_Bool values[6]={0,0,0,0,0,0};

	//run_motor(0);

	//run_motor(2);


    // Počisti UART3 buffer
    memset((void*)uart3_rx_buffer, 0, 32);
    uart3_rx_index = 0;
    uart3_command_ready = 0;
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

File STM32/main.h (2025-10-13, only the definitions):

#define SDRAM_WRITE_READ_ADDR        ((uint32_t)0xD0177000)
#define SDRAM_WRITE_READ_ADDR_OFFSET ((uint32_t)0x0800)
#define PAUSE_STATUS     ((uint32_t)0x00) /* Audio Player in Pause Status */
#define RESUME_STATUS    ((uint32_t)0x01) /* Audio Player in Resume Status */
#define IDLE_STATUS      ((uint32_t)0x02) /* Audio Player in Idle Status */
#define LED_GREEN      LED1
#define LED_RED        LED2
#define AUDIO_REC_START_ADDR         SDRAM_WRITE_READ_ADDR
#define AUDIO_REC_TOTAL_SIZE         ((uint32_t) 0x0000E000)
#define AUDIO_RECPDM_START_ADDR      (AUDIO_REC_START_ADDR+AUDIO_REC_TOTAL_SIZE)
#define AUDIO_SRC_FILE_ADDRESS       0x90080000   /* Audio file address in flash */
#define AUDIO_FILE_SIZE              0x80000
#define AUDIO_PLAY_SAMPLE        0
#define AUDIO_PLAY_RECORDED      1
#define FDCAN2_RX_Pin GPIO_PIN_5
#define FDCAN2_RX_GPIO_Port GPIOB
#define SDIO1_D2_Pin GPIO_PIN_10
#define SDIO1_D2_GPIO_Port GPIOC
#define MII_TX_EN_Pin GPIO_PIN_11
#define MII_TX_EN_GPIO_Port GPIOG
#define LCD_DISP_Pin GPIO_PIN_15
#define LCD_DISP_GPIO_Port GPIOJ
#define SDIO1_D3_Pin GPIO_PIN_11
#define SDIO1_D3_GPIO_Port GPIOC
#define FDCAN1_RX_Pin GPIO_PIN_14
#define FDCAN1_RX_GPIO_Port GPIOH
#define OSC32_OUT_Pin GPIO_PIN_15
#define OSC32_OUT_GPIO_Port GPIOC
#define OSC32_IN_Pin GPIO_PIN_14
#define OSC32_IN_GPIO_Port GPIOC
#define MII_TXD3_Pin GPIO_PIN_2
#define MII_TXD3_GPIO_Port GPIOE
#define MII_TXD1_Pin GPIO_PIN_12
#define MII_TXD1_GPIO_Port GPIOG
#define LCD_DISPD7_Pin GPIO_PIN_7
#define LCD_DISPD7_GPIO_Port GPIOD
#define SDIO1_CK_Pin GPIO_PIN_12
#define SDIO1_CK_GPIO_Port GPIOC
#define SDIO1_D5_Pin GPIO_PIN_9
#define SDIO1_D5_GPIO_Port GPIOB
#define SDIO1_D4_Pin GPIO_PIN_8
#define SDIO1_D4_GPIO_Port GPIOB
#define SDIO1_D4_Pin GPIO_PIN_8
#define SDIO1_D4_GPIO_Port GPIOB
#define MII_TXD0_Pin GPIO_PIN_13
#define MII_TXD0_GPIO_Port GPIOG
#define SDIO1_CMD_Pin GPIO_PIN_2
#define SDIO1_CMD_GPIO_Port GPIOD
#define USB_OTG_FS2_ID_Pin GPIO_PIN_10
#define USB_OTG_FS2_ID_GPIO_Port GPIOA
#define VBUS_FS2_Pin GPIO_PIN_9
#define VBUS_FS2_GPIO_Port GPIOA
#define FDCAN1_TX_Pin GPIO_PIN_13
#define FDCAN1_TX_GPIO_Port GPIOH
#define B1_Pin GPIO_PIN_13
#define B1_GPIO_Port GPIOC
#define SDIO1_D0_Pin GPIO_PIN_8
#define SDIO1_D0_GPIO_Port GPIOC
#define SDIO1_D1_Pin GPIO_PIN_9
#define SDIO1_D1_GPIO_Port GPIOC
#define USB_OTG_FS2_P_Pin GPIO_PIN_12
#define USB_OTG_FS2_P_GPIO_Port GPIOA
#define USB_OTG_FS2_N_Pin GPIO_PIN_11
#define USB_OTG_FS2_N_GPIO_Port GPIOA
#define MII_RX_ER_Pin GPIO_PIN_10
#define MII_RX_ER_GPIO_Port GPIOI
#define SDIO1_D7_Pin GPIO_PIN_7
#define SDIO1_D7_GPIO_Port GPIOC
#define SDIO1_D6_Pin GPIO_PIN_6
#define SDIO1_D6_GPIO_Port GPIOC
#define audio_Int_Pin GPIO_PIN_7
#define audio_Int_GPIO_Port GPIOG
#define LD2_Pin GPIO_PIN_13
#define LD2_GPIO_Port GPIOI
#define LCD_INT_Pin GPIO_PIN_2
#define LCD_INT_GPIO_Port GPIOG
#define OSC_OUT_Pin GPIO_PIN_1
#define OSC_OUT_GPIO_Port GPIOH
#define OSC_IN_Pin GPIO_PIN_0
#define OSC_IN_GPIO_Port GPIOH
#define LCD_BL_Pin GPIO_PIN_0
#define LCD_BL_GPIO_Port GPIOK
#define MII_MDC_Pin GPIO_PIN_1
#define MII_MDC_GPIO_Port GPIOC
#define MII_TXD2_Pin GPIO_PIN_2
#define MII_TXD2_GPIO_Port GPIOC
#define MII_TX_CLK_Pin GPIO_PIN_3
#define MII_TX_CLK_GPIO_Port GPIOC
#define MII_CRS_Pin GPIO_PIN_2
#define MII_CRS_GPIO_Port GPIOH
#define MII_MDIO_Pin GPIO_PIN_2
#define MII_MDIO_GPIO_Port GPIOA
#define MII_RX_CLK_Pin GPIO_PIN_1
#define MII_RX_CLK_GPIO_Port GPIOA
#define MII_COL_Pin GPIO_PIN_3
#define MII_COL_GPIO_Port GPIOH
#define VCP_TX_Pin GPIO_PIN_10
#define VCP_TX_GPIO_Port GPIOB
#define VCP_RX_Pin GPIO_PIN_11
#define VCP_RX_GPIO_Port GPIOB
#define OTG_FS2_OverCurrent_Pin GPIO_PIN_11
#define OTG_FS2_OverCurrent_GPIO_Port GPIOH
#define MII_RX_DV_Pin GPIO_PIN_7
#define MII_RX_DV_GPIO_Port GPIOA
#define MII_TX_ER_nINT_Pin GPIO_PIN_2
#define MII_TX_ER_nINT_GPIO_Port GPIOB
#define OTG_FS2_PSO_Pin GPIO_PIN_5
#define OTG_FS2_PSO_GPIO_Port GPIOA
#define MII_RXD0_Pin GPIO_PIN_4
#define MII_RXD0_GPIO_Port GPIOC
#define MII_RX_D3_Pin GPIO_PIN_1
#define MII_RX_D3_GPIO_Port GPIOB
#define LD1_Pin GPIO_PIN_2
#define LD1_GPIO_Port GPIOJ
#define LCD_RST_Pin GPIO_PIN_12
#define LCD_RST_GPIO_Port GPIOB
#define MII_RXD1_Pin GPIO_PIN_5
#define MII_RXD1_GPIO_Port GPIOC
#define MII_RX_D2_Pin GPIO_PIN_0
#define MII_RX_D2_GPIO_Port GPIOB
#define FDCAN2_TX_Pin GPIO_PIN_13
#define FDCAN2_TX_GPIO_Port GPIOB

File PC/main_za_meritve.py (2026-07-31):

#!/usr/bin/env python3
# -*- coding: utf-8 -*-

"""
Združena koda: mobilna platforma + segmentacija z RealSense in CLIPSeg.
- Gamepad krmiljenje (hitrost, zavijanje z D-pad, načini, varnost)
- PLC komunikacija prek ADS
- RB (gumb 5) takoj odpre/zapre okno s preview in nastavi mode 5
- A (gumb 0) v preview sproži segmentacijo; v rezultatu sprejme koordinate in začne merilni protokol
- B (gumb 1) v rezultatu zavrne in vrne v preview
- Back (gumb 6) pošlje kalibracijski ukaz na STM32
- Med odprtim oknom je vožnja zaustavljena
- UART komunikacija: pošiljanje brez \r\n, branje odgovorov
- Merilni protokol: MERITEV 1–5 s časovnimi žigi, shranjevanje v CSV, graf razdalje in pritiska
- MERITEV 4 zbira tlake, MERITEV 5 je premik nazaj
- Sporočilo "MERITEV ZAKLJUCENA" takoj zaključi meritev in pripravi sistem za novo vožnjo
- Sporočilo "MERITEV SENSOR FAIL" zaključi MERITEV 3 in nadaljuje na MERITEV 5
- Čas segmentacije (korak 0) se shrani takoj na začetku (ne ponastavlja se ob start_measurement_step(1))
- CSV se ustvari na začetku in dopolnjuje sproti (takoj flush na disk)
- D-pad desno med meritvijo sproži zaključek in pospravljanje
- Prekinitev (gumb B, D-pad desno) pošlje MERITEV KONEC in čaka na MERITEV 5 STOP
"""

import os
import sys
import time
import math
import threading
import numpy as np
import cv2
import torch
import pygame
import pyads
import serial
import pyrealsense2 as rs
from transformers import CLIPSegProcessor, CLIPSegForImageSegmentation
import csv
import matplotlib.pyplot as plt
import re

# ==============================================================================
# NASTAVITVE OKOLJA
# ==============================================================================
os.environ["CUDA_VISIBLE_DEVICES"] = ""
os.environ["HF_TOKEN"] = ""
os.environ['PYGAME_HIDE_SUPPORT_PROMPT'] = "hide"

try:
    sys.modules['torchaudio'] = None
except Exception:   
    pass

# ==============================================================================
# KONFIGURACIJA
# ==============================================================================
SERIAL_PORT = 'COM3'
BAUD_RATE = 115200
UART_LOG_FILE = "uart_timestamps.txt"

MIN_DISTANCE_MM = 200
MAX_DISTANCE_MM = 400
ENABLE_AVERAGING = False
NUM_SAMPLES = 7

X_SCALE = 1.0
X_OFFSET_MM = 0
Y_SCALE = 1.0
Y_OFFSET_MM = 0
Z_HEIGHT_MM = 100

LOKALNI_AMS_ID = "192.168.65.121.1.1"
PLC_IP = "192.168.64.200"
PLC_AMS_ID = "169.254.220.1.1.1"

STEP_NAMES = {
    0: "Segmentacija",
    1: "Premik do debla",
    2: "Igla do debla",
    3: "Igla v deblo",
    4: "Črpanje tekočine",
    5: "Premik v domačo lego"
}

# --- Globalne spremenljivke ---
set_speed = 50
current_angle = 0.0
old_current_angle = 0.0
delta_angle = 0.0
max_angle = 30.0
angle_step = 10
mode_change_requested = False
timestamp_temp = 0
cycle_timestamp = 0

pipeline = None
align = None
depth_scale = None
intrinsics = None
device = "cpu"
processor = None
model = None
spatial_filter = None
hole_filling = None

vision_window_open = False
vision_preview_mode = True
vision_segmentation_result = None
vision_lock = threading.Lock()
last_color_frame = None
last_depth_frame = None

# UART
uart_ser = None
uart_lock = threading.Lock()
uart_sending = threading.Event()
exit_pending = False          # ni v uporabi

# Merilni protokol
measurement_state = "idle"          # idle, meas1, wait1, meas2, wait2, meas3, wait3, meas4_pressure, meas4_stop, meas5, wait5, done, aborted
measurement_folder = None           # trenutna mapa za meritve (ustvari se ob segmentaciji)
measurement_run_counter = 0
measurement_times = []              # seznam dict za vsak korak: {'step':int, 'start':float, 'stop':float, 'elapsed':float}
measurement_distances = []          # seznam (timestamp, razdalja_mm) za MERITEV 3
measurement_pressures = []          # seznam (timestamp, pressure_bar) za MERITEV 4
measurement_step_start = None
measurement_step_number = 0
measurement_total_time = 0.0
measurement_aborted = False
measurement_waiting_for_approval = False

# --- NOVE GLOBALNE SPREMENLJIVKE ZA NAČIN ČIŠČENJA ---
measurement_cleanup_mode = False     # ali smo v načinu pospravljanja po prekinitvi
measurement_cleanup_start = None     # začetni čas pospravljanja
# ----------------------------------------------------

segmentation_elapsed = 0.0          # čas segmentacije (od pritiska A do konca obdelave)
seg_start=0.0
seg_stop=0.0
meas3_start_time = None             # začetni čas MERITEV 3 (za graf razdalje)
meas4_start_time = None             # začetni čas MERITEV 4 (za graf pritiska)
times_csv_writer = None             # CSV writer za sprotno pisanje
times_csv_file_handle = None        # Odprti datotečni objekt za flush
times_csv_file = None               # Ime datoteke (za izpis)

# UART sporočila iz poslušalca
uart_messages = []
uart_messages_lock = threading.Lock()

# ==============================================================================
# FUNKCIJE ZA UART
# ==============================================================================
def uart_log_timestamp(keyword):
    timestamp = time.time()
    try:
        with open(UART_LOG_FILE, 'a') as f:
            f.write(f"{timestamp:.6f} - {keyword}\n")
        print(f"[UART LOG] {keyword} @ {timestamp:.6f}")
    except Exception as e:
        print(f"[UART LOG] Napaka pri pisanju: {e}")
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

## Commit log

2025-08-27 Update and rename main.c to STM32/main.c
2025-10-19 Fix import statements in main.py
    [main.py]
2025-10-19 Correct message receiving logic in spik_bot_serial.py
    Fix indentation and return statement in receiving message logic.
    [spik_bot_serial.py]
2025-12-18 Add cylinder detection and 3D coordinate calculation
2026-05-11 Update and rename STM32/trenutno_testiram_tole.c to STM32/trenutno_testiram_tole/trenutno_testiram_tole.c
2026-05-19 Refactor motor control logic and add test cases
    Comment out unused code and add test sequences for motor control.
2026-05-22 stabilen tof in h bridge. Flag za uart dodan
2026-07-01 Update and rename unit_testing.c to motor_dela_obe_smeri.c
2026-08-11 Update print statement from 'Hello' to 'Goodbye'
2026-08-11 Update fmt.Println message from 'Hello' to 'Goodbye'

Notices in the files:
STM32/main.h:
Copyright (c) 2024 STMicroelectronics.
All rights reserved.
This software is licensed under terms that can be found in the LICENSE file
